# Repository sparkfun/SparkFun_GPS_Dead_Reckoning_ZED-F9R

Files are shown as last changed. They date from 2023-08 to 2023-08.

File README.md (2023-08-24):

SparkFun GPS-RTK Dead Reckoning Breakout - ZED-F9R, u.FL and SMA (Qwiic)
========================================

<table class="table table-hover table-striped table-bordered">
  <tr align="center">
   <td><a href="https://www.sparkfun.com/products/22693">SparkFun GPS-RTK Dead Reckoning Breakout - ZED-F9R (Qwiic)</a></td>
   <td><a href="https://www.sparkfun.com/products/22660">SparkFun GPS-RTK Dead Reckoning Breakout - ZED-F9R, SMA (Qwiic)</a></td>
  </tr>
  <tr align="center">
   <td><i>SparkFun GPS-RTK Dead Reckoning Breakout <br /> - ZED-F9R, u.FL (Qwiic) [<a href="https://www.sparkfun.com/products/22693">22693</a>]</i></td>
   <td><i>SparkFun GPS-RTK Dead Reckoning Breakout <br /> - ZED-F9R, SMA (Qwiic) [<a href="https://www.sparkfun.com/products/22660">GPS-22660</a>]</i></td>
  </tr>
</table>

The SparkFun GPS-RTK Dead Reckoning ZED-F9R Breakout (u.FL and SMA) is a high precision, sensor fusion GPS board with equally impressive configuration options and takes advantage of u-blox's Automotive Dead Reckoning (ADR) technology. The ZED-F9R module provides a highly accurate and continuous position by fusing a 3D IMU sensor, wheel ticks, a vehicle dynamics model, correction data, and GNSS measurements.

The ZED-F9R module is a 184-channel u-blox F9 engine GNSS receiver, meaning it can receive signals from the GPS, GLONASS, Galileo, and BeiDou constellations with ~0.2 meter accuracy! That's right, such accuracy can be achieved with an RTK navigation solution when used with a correction source. Note that the ZED-F9R can only operate as a rover, so you will need to connect to a base station. The module supports concurrent reception of four GNSS systems. The combination of GNSS and integrated 3D sensor measurements on the ZED-F9R provide accurate, real-time positioning rates of up to 30Hz.

Compared to other GPS modules, this breakout maximizes position accuracy in dense cities or covered areas. Even under poor signal conditions, continuous positioning is provided in urban environments and is also available during complete signal loss (e.g. short tunnels and parking garages). The ZED-F9R is the ultimate solution for autonomous robotic applications that require accurate positioning under challenging conditions.

Additionally, this u-blox receiver supports I2C (u-blox calls this Display Data Channel) which makes it perfect for the Qwiic compatibility so we don't have to use up our precious UART ports. Utilizing our handy Qwiic system, no soldering is required to connect it to the rest of your system. However, we still have broken out 0.1"-spaced pins in case you prefer to use a breadboard.

U-blox based GPS products are configurable using the popular, but dense, windows program called u-center. Plenty of different functions can be configured on the ZED-F9R: baud rates, update rates, geofencing, spoofing detection, external interrupts, SBAS/D-GPS, etc. All of this can be done within the SparkFun Arduino Library!

The SparkFun ZED-F9R GPS Breakout is also equipped with an on-board rechargeable battery that provides power to the RTC on the ZED-F9R. This reduces the time-to-first fix from a cold start (~24s) to a hot start (~2s). The battery will maintain RTC and GNSS orbit data without being connected to power for plenty of time.

Repository Contents
-------------------

* **/Documentation** - Data sheets, additional product information
* **/Hardware** - Eagle design files (.brd, .sch)
* **/Production** - Production panel files (.brd)

Documentation
--------------
* **[Library](https://github.com/sparkfun/SparkFun_u-blox_GNSS_v3)** - Arduino library v3 for the ZED-F9R.
    * _**Note**: We support two versions of the SparkFun u-blox GNSS library. [Version 2](https://github.com/sparkfun/SparkFun_u-blox_GNSS_Arduino_Library) and [Version 3](https://github.com/sparkfun/SparkFun_u-blox_GNSS_v3). Version 3 uses the u-blox Configuration Interface (VALSET and VALGET) to configure the module, instead of the deprecated UBX-CFG messages. For modules like the F9 and M10, we recommend upgrading to Version 3. However, older modules like the M8 do not support the Configuration Interface. For those you will need to keep using Version 2 of the library. We will continue to support both._
* **[Hookup Guide](https://learn.sparkfun.com/tutorials/1172)** - Basic hookup guide for the ZED-F9R.

Product Versions
----------------
* [GPS-22693](https://www.sparkfun.com/products/22693) - u.FL, v1.2
* [GPS-22660](https://www.sparkfun.com/products/22660) - SMA, V1.1
* [GPS-16344](https://www.sparkfun.com/products/16344) - u.FL, v1.0 initial release

Version History
---------------
* [v1.0](https://github.com/sparkfun/SparkFun_GPS_Dead_Reckoning_ZED-F9R/releases/tag/v1.0) - Initial Release

License Information
-------------------

This product is _**open source**_! 

Please review the LICENSE.md file for license information. 

If you have any questions or concerns on licensing, please contact technical support on our [SparkFun forums](https://forum.sparkfun.com/viewforum.php?f=152).

Distributed as-is; no warranty is given.

- Your friends at SparkFun.

_<COLLABORATION CREDIT>_

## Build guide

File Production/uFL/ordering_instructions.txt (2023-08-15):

panel size, 101x124mm
PCB thickness, 1.6mm
number of layers, 2
soldermask color, Red
silkscreen color, White
oz copper, 1oz
finish, HASL lead free
stencils, top
pcs per panel, 4
min trace width, 0.1524mm / 0.0060in
min drill size, 0.3048mm / 0.0120in

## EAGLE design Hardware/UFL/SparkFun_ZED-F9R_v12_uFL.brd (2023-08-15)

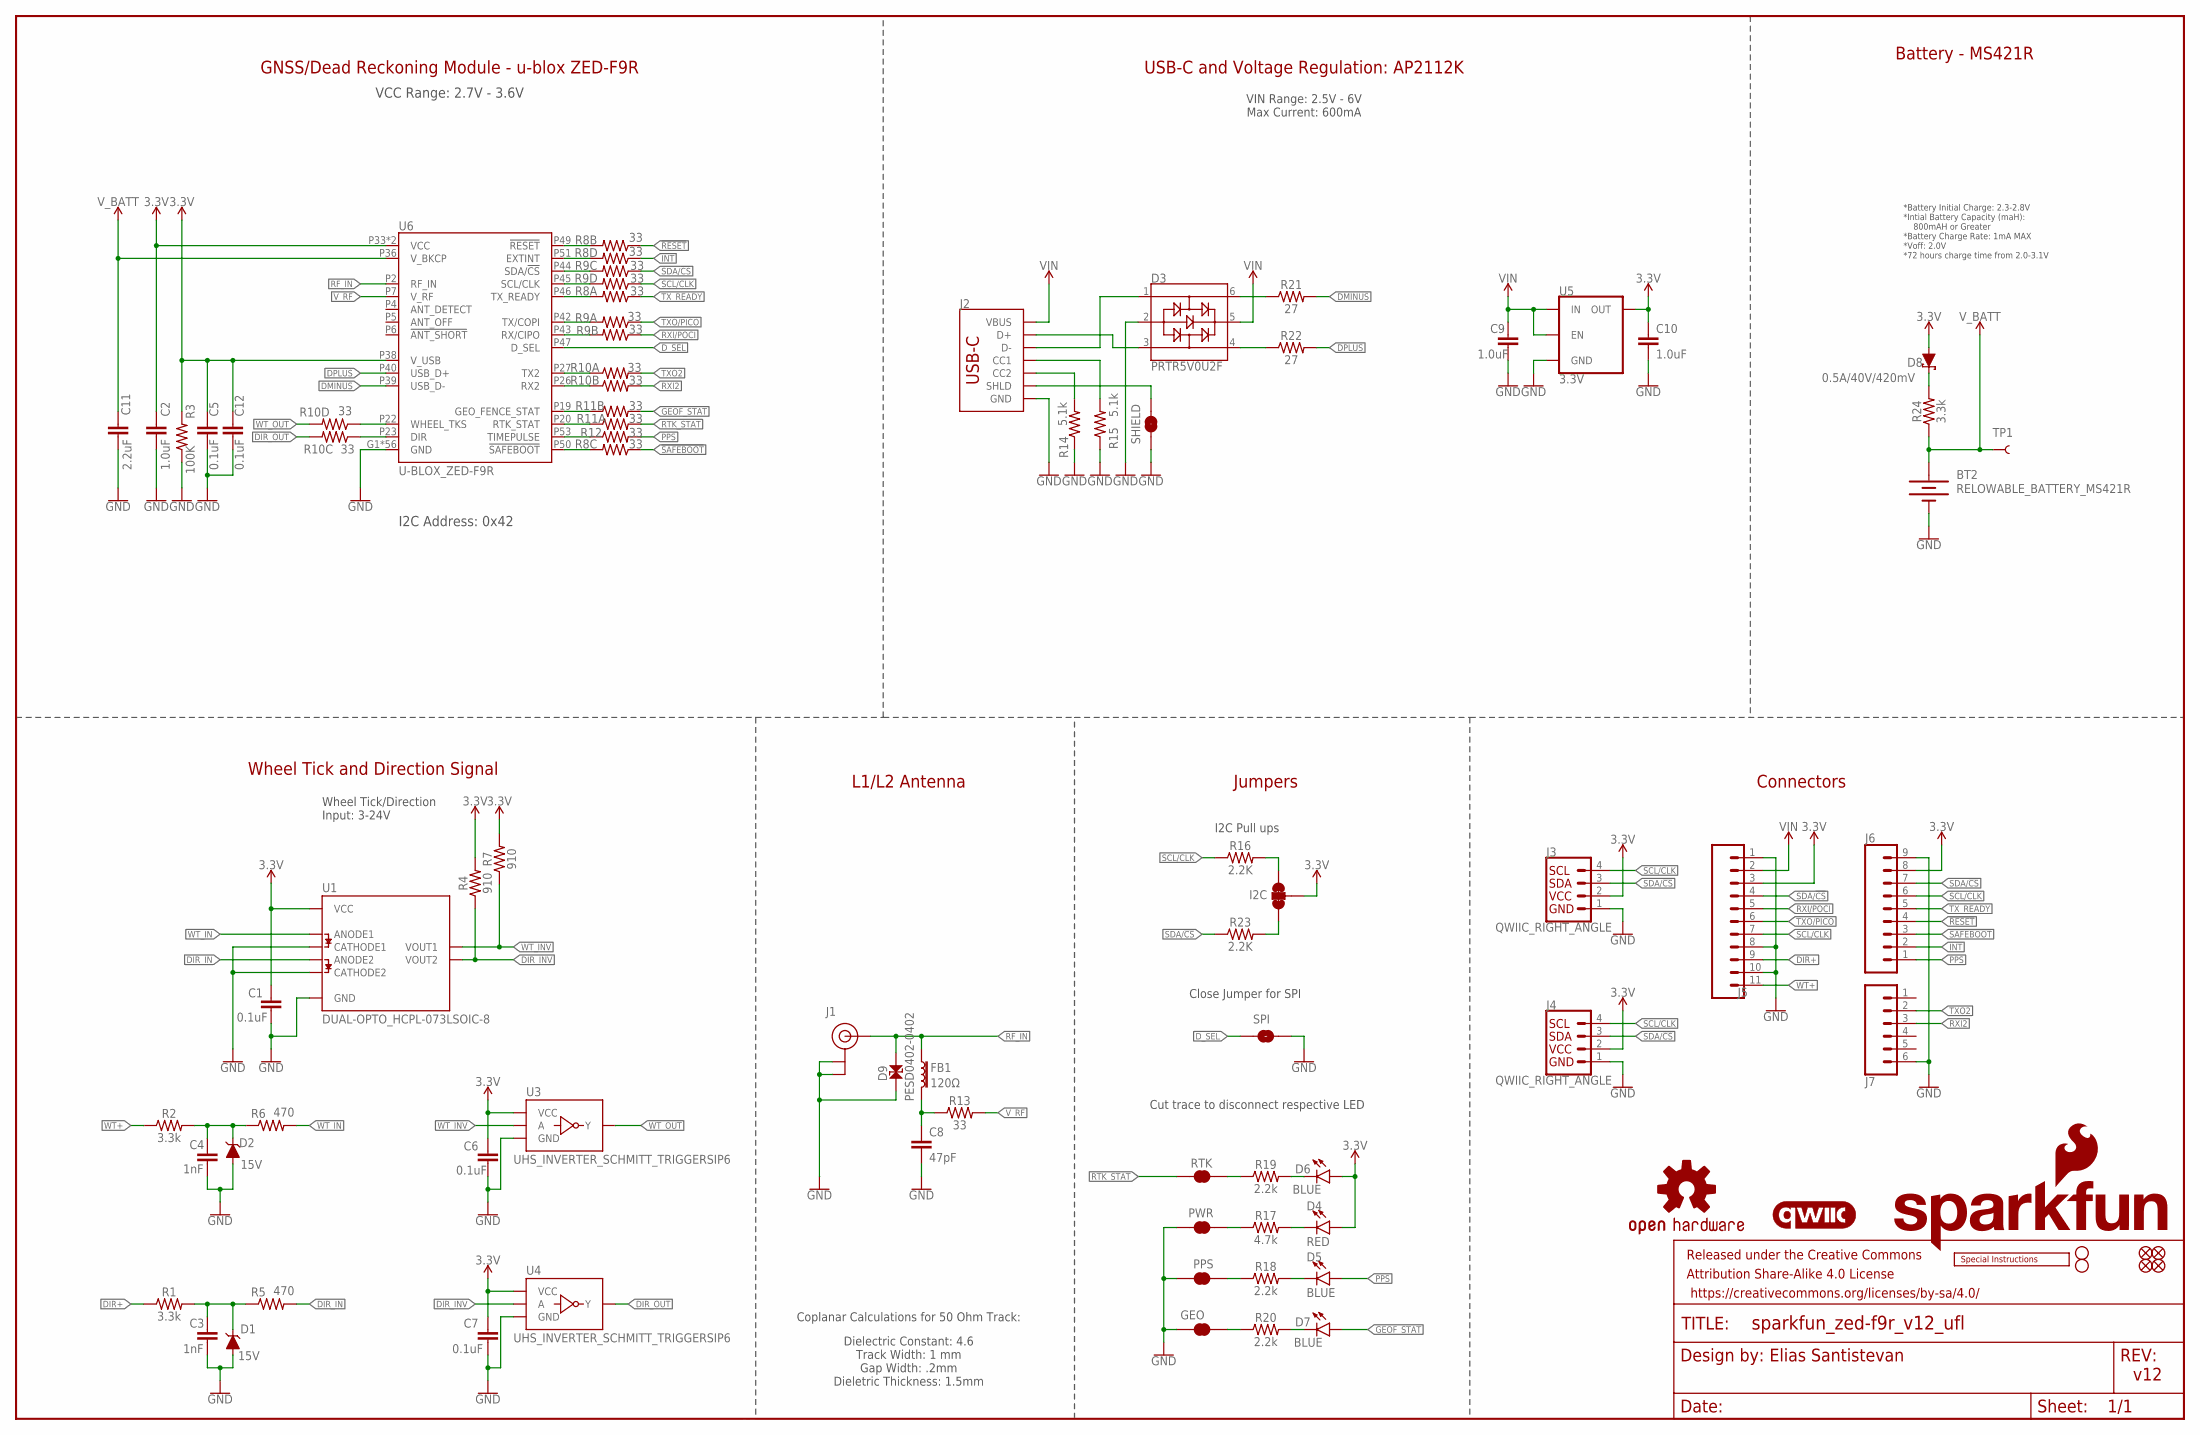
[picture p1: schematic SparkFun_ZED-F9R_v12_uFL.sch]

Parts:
$1_25_$_2020-03-30_22-52-05: STAND-OFFTIGHT; STAND-OFF-TIGHT
BT2: RELOWABLE_BATTERY_MS421R; MS421R_IV03E
C1, C5, C6, C7, C12: 0.1uF; 0402-TIGHT
C2, C9, C10: 1.0uF; 0402-TIGHT
C3, C4: 1nF; 0402
C8: 47pF; 0402
C11: 2.2uF; 0402-TIGHT
D1, D2: 15V; SOT23-3
D3: PRTR5V0U2F; SOT886
D4: RED; LED-0603
D5, D6, D7: BLUE; LED-0603
D8: 0.5A/40V/420mV; SOD-323
D9: PESD0402-0402; 0402
FB1: 120Ω; 0402
FD1, FD2, FD3, FD4: FIDUCIALUFIDUCIAL; FIDUCIAL-MICRO
FRAME1: FRAME-LEDGER; CREATIVE_COMMONS
GEO: JUMPER-SMT_2_NC_TRACE_SILK; SMT-JUMPER_2_NC_TRACE_SILK
H2: STAND-OFFTIGHT; STAND-OFF-TIGHT
I2C: JUMPER-SMT_3_2-NC_TRACE_SILK; SMT-JUMPER_3_2-NC_TRACE_SILK
J1: U.FL
J2: USB_C_2-LAYER_PADS; USB-C-16P-2LAYER-PADS
J3, J4: QWIIC_RIGHT_ANGLE; JST04_1MM_RA
J5: CONN_111X11_NO_SILK; 1X11_NO_SILK
J6: CONN_09NO_SILK; 1X09_NO_SILK
J7: CONN_06NO_SILK_NO_POP; 1X06_NO_SILK
LOGO1: OSHW-LOGOS; OSHW-LOGO-S
LOGO2: QWIIC_LOGO_4MM; QWIIC_4MM
LOGO3: SFE_LOGO_NAME_FLAME.2_INCH; SFE_LOGO_NAME_FLAME_.2
LOGO5: SPECIAL_INSTRUCTIONS-ORDERING; ORDERING_INSTRUCTIONS
PPS: JUMPER-SMT_2_NC_TRACE_SILK; SMT-JUMPER_2_NC_TRACE_SILK
PWR: JUMPER-SMT_2_NC_TRACE_SILK; SMT-JUMPER_2_NC_TRACE_SILK
R1, R2, R24: 3.3k; 0603
R3: 100K; 0402
R4, R7: 910; 0603
R5, R6: 470; 0603
R8, R9, R10, R11: 33; 1206_RA
R12, R13: 33; 0603
R14, R15: 5.1k; 0402
R16, R23: 2.2K; 0402
R17: 4.7k; 0603
R18, R19, R20: 2.2k; 0603
R21, R22: 27; 0603
RTK: JUMPER-SMT_2_NC_TRACE_SILK; SMT-JUMPER_2_NC_TRACE_SILK
SHIELD: JUMPER-SMT_2_NC_TRACE_SILK; SMT-JUMPER_2_NC_TRACE_SILK
SPI: JUMPER-SMT_2_NO_SILK; SMT-JUMPER_2_NO_SILK
TP1: TEST-POINT3X5; PAD.03X.05
U1: DUAL-OPTO_HCPL-073LSOIC-8; SO08
U3, U4: UHS_INVERTER_SCHMITT_TRIGGERSIP6; SIP6_MICROPAK2
U5: 3.3V; SOT23-5
U6: U-BLOX_ZED-F9R; UBLOX_ZED_F9R

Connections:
3.3V: C1.1, C2.1, C5.1, C6.1, C7.1, C10.1, C12.1, D4.A, D6.A, D8.A, I2C.2, J3.2, J4.2, J5.3, J6.8, R3.2, R4.2, R7.2, U1.8 (VCC), U3.P6 (VCC), U4.P6 (VCC), U5.5 (OUT), U6.P33 (VCC), U6.P34 (VCC), U6.P38 (V_USB)
!RESET: J6.4, R8.P2 (1)
!SAFEBOOT: J6.3, R8.P3 (1)
DIR+: J5.9, R1.1
DIR_IN: R5.2, U1.4 (ANODE2)
DIR_INV: R4.1, U1.6 (VOUT2), U4.P2 (A)
DIR_OUT: R10.P6 (2), U4.P4 (Y)
DMINUS: R21.2, U6.P39 (USB_D-)
DPLUS: R22.2, U6.P40 (USB_D+)
D_SEL: SPI.1, U6.P47 (D_SEL)
GEOF_STAT: D7.A, R11.P7 (2)
GND: BT2.-, C1.2, C2.2, C3.2, C4.2, C5.2, C6.2, C7.2, C8.2, C9.2, C10.2, C11.2, C12.2, D1.1 (A), D2.1 (A), D3.2, D9.1, GEO.1, J1.1 (GND), J1.2 (GND), J2.GND, J2.GND2 (GND), J3.1, J4.1, J5.1, J5.8, J5.10, J6.9, J7.6, PPS.1, PWR.1, R3.1, R14.1, R15.1, SHIELD.1, SPI.2, U1.2 (CATHODE1), U1.3 (CATHODE2), U1.5 (GND), U3.P3 (GND), U4.P3 (GND), U5.2 (GND), U6.G1 (GND), U6.G2 (GND), U6.G3 (GND), U6.G4 (GND), U6.G5 (GND), U6.G6 (GND), U6.G7 (GND), U6.G8 (GND), U6.G9 (GND), U6.G10 (GND), U6.G11 (GND), U6.G12 (GND), U6.G13 (GND), U6.G14 (GND), U6.G15 (GND), U6.G16 (GND), U6.G17 (GND), U6.G18 (GND), U6.G19 (GND), U6.G20 (GND), U6.G21 (GND), U6.G22 (GND), U6.G23 (GND), U6.G24 (GND), U6.G25 (GND), U6.G26 (GND), U6.G27 (GND), U6.G28 (GND), U6.G29 (GND), U6.G30 (GND), U6.G31 (GND), U6.G32 (GND), U6.G33 (GND), U6.G34 (GND), U6.G35 (GND), U6.G36 (GND), U6.G37 (GND), U6.G38 (GND), U6.G39 (GND), U6.G40 (GND), U6.G41 (GND), U6.G42 (GND), U6.G43 (GND), U6.G44 (GND), U6.G45 (GND), U6.G46 (GND), U6.G47 (GND), U6.G48 (GND), U6.P1 (GND), U6.P3 (GND), U6.P12 (GND), U6.P14 (GND), U6.P32 (GND), U6.P37 (GND), U6.P41 (GND), U6.P48 (GND)
INT: J6.2, R8.P4 (1)
unnamed: I2C.1, R23.2
unnamed: D8.C, R24.2
unnamed: I2C.3, R16.2
unnamed: D4.C, R17.2
unnamed: C8.1, FB1.2, R13.1
unnamed: D3.3, J2.A6 (D+), J2.B6 (D+)
unnamed: D3.1, J2.A7 (D-), J2.B7 (D-)
unnamed: PWR.2, R17.1
unnamed: D3.6, R21.1
unnamed: D3.4, R22.1
unnamed: R8.P7 (2), U6.P49 (!RESET!)
unnamed: R8.P5 (2), U6.P51 (EXTINT)
unnamed: J2.B5 (CC2), R14.2
unnamed: J2.A5 (CC1), R15.2
unnamed: R9.P6 (2), U6.P44 (SDA/!CS!)
unnamed: R9.P5 (2), U6.P45 (SCL/CLK)
unnamed: R8.P8 (2), U6.P46 (TX_READY)
unnamed: R9.P8 (2), U6.P42 (TX/COPI)
unnamed: R9.P7 (2), U6.P43 (RX/CIPO)
unnamed: R10.P1 (1), U6.P27 (TX2)
unnamed: R19.1, RTK.2
unnamed: PPS.2, R18.1
unnamed: D5.C, R18.2
unnamed: D6.C, R19.2
unnamed: R10.P2 (1), U6.P26 (RX2)
unnamed: R11.P2 (1), U6.P19 (GEO_FENCE_STAT)
unnamed: R11.P1 (1), U6.P20 (RTK_STAT)
unnamed: R12.1, U6.P53 (TIMEPULSE)
unnamed: R8.P6 (2), U6.P50 (!SAFEBOOT!)
unnamed: R10.P4 (1), U6.P22 (WHEEL_TKS)
unnamed: R10.P3 (1), U6.P23 (DIR)
unnamed: GEO.2, R20.1
unnamed: D7.C, R20.2
unnamed: C4.1, D2.3 (C), R2.2, R6.1
unnamed: C3.1, D1.3 (C), R1.2, R5.1
PPS: D5.A, J6.1, R12.2
RF_IN: D9.2, FB1.1, J1.FEED (SIGNAL), U6.P2 (RF_IN)
RTK_STAT: R11.P8 (2), RTK.1
RXI2: J7.3, R10.P7 (2)
RXI/POCI: J5.5, R9.P2 (1)
SCL/CLK: J3.4, J4.4, J5.7, J6.6, R9.P4 (1), R16.1
SDA/!CS: J3.3, J4.3, J5.4, J6.7, R9.P3 (1), R23.1
SHIELD: J2.SHLD1 (SHLD), J2.SHLD2 (SHLD), J2.SHLD3 (SHLD), J2.SHLD4 (SHLD), SHIELD.2
TXO2: J7.2, R10.P8 (2)
TXO/PICO: J5.6, R9.P1 (1)
TX_READY: J6.5, R8.P1 (1)
VIN: C9.1, D3.5, J2.VBUS1 (VBUS), J2.VBUS2 (VBUS), J5.2, U5.1 (IN), U5.3 (EN)
V_BATT: BT2.+, C11.1, R24.1, TP1.1, U6.P36 (V_BKCP)
V_RF: R13.2, U6.P7 (V_RF)
WT+: J5.11, R2.1
WT_IN: R6.2, U1.1 (ANODE1)
WT_INV: R7.1, U1.7 (VOUT1), U3.P2 (A)
WT_OUT: R10.P5 (2), U3.P4 (Y)

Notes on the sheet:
v12
Elias Santistevan
GNSS/Dead Reckoning Module - u-blox ZED-F9R
Battery - MS421R
Connectors
Jumpers
Close Jumper for SPI
I2C Pull ups
Cut trace to disconnect respective LED
L1/L2 Antenna
*Battery Initial Charge: 2.3-2.8V *Intial Battery Capacity (maH): 800mAH or Greater *Battery Charge Rate: 1mA MAX *Voff: 2.0V *72 hours charge time from 2.0-3.1V
VIN Range: 2.5V - 6V Max Current: 600mA
USB-C and Voltage Regulation: AP2112K
VCC Range: 2.7V - 3.6V
I2C Address: 0x42
Wheel Tick and Direction Signal
Wheel Tick/Direction Input: 3-24V
Coplanar Calculations for 50 Ohm Track:
Dielectric Constant: 4.6 Track Width: 1 mm Gap Width: .2mm Dieletric Thickness: 1.5mm

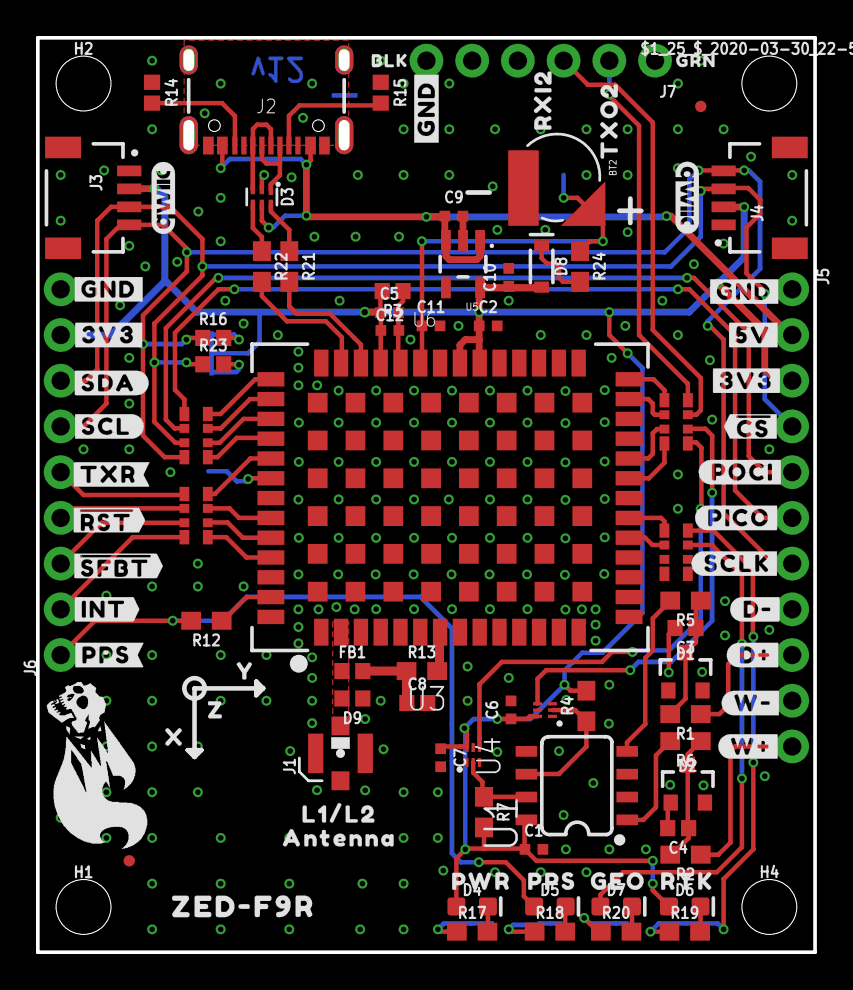
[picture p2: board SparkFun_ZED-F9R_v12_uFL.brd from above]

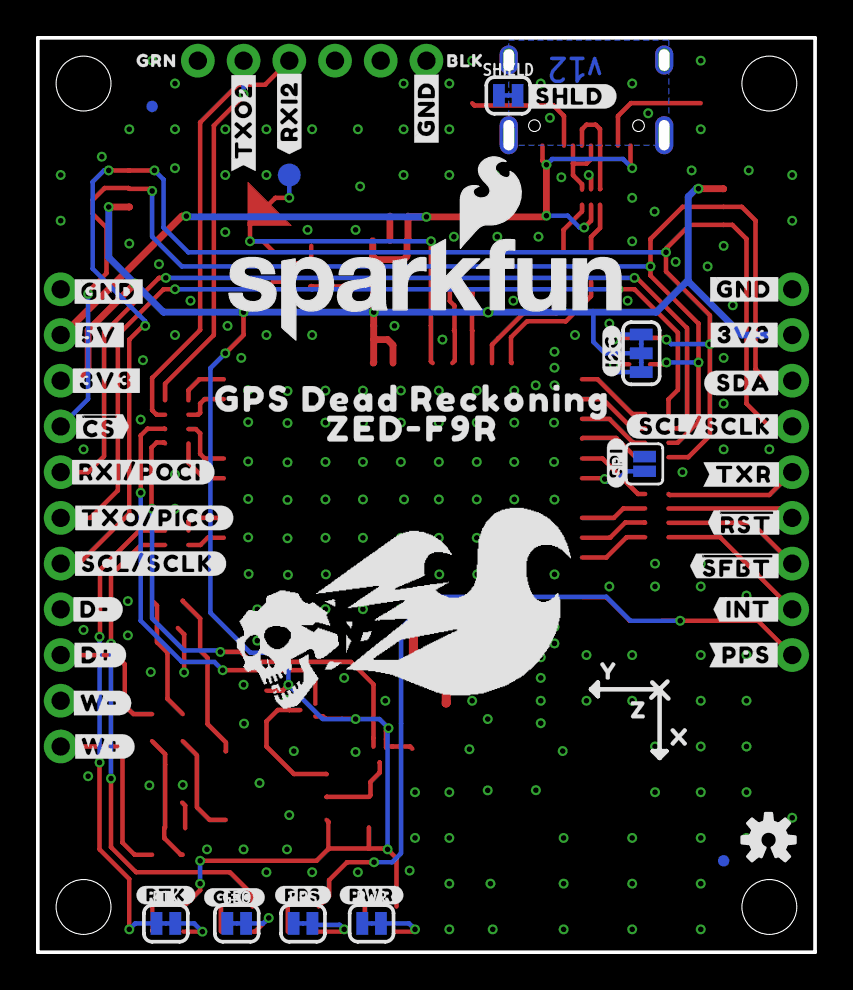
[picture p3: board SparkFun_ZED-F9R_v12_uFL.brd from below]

Board: 2 copper layers, 43.2 x 50.8 mm, 155 parts (50 on the bottom side), 66 nets.

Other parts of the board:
H1, H4: STAND-OFFTIGHT; STAND-OFF-TIGHT
LOGO4: QWIIC_LOGO_4MM; QWIIC_4MM
U$1: ZED#F9R21
U$2: L1#L26
U$3: ANTENNA6
U$4, U$32: X17
U$5, U$6, U$7, U$8, U$9, U$67: #GND#16
U$10: #D##241
U$11: #D##240
U$12: #W##244
U$13: #W##245
U$14, U$15, U$16, U$17: #3V3#17
U$18, U$21: #5V#17
U$19, U$20: DEAD#RECKONING#GPS#BOARD#SILK#FINAL#JPG
U$22: #SDA#235
U$23, U$71: BLK18
U$24: ##CS##25
U$26, U$70: GRN19
U$27: #SDA#236
U$28: #SCL#238
U$29: #TXR#248
U$30: ##RST##28
U$31: ##SFBT##26
U$33: #INT#1
U$34: #INT#0
U$35: #PPS#3
U$37: #SCLK#233
U$38: RXI229
U$39: PWR6
U$40: RTK12
U$41: GEO10
U$42: PPS8
U$43, U$44: Z19
U$45, U$49: Y18
U$46: #SCL#SCLK#2244
U$47: #GEO#12
U$48: #RTK#14
U$50: TXO2234
U$51: #PPS#10
U$52: ##CS##26
U$53: #SPI#4
U$54: #I2C#5
U$57: #SCL#SCLK#2243
U$58: #D##2249
U$59: #D##2248
U$60: #W##2253
U$61: #W##2252
U$62: #TXR#2255
U$63: ##RST##27
U$64: ##SFBT##29
U$65: #PPS#2
U$66: #PWR#8
U$68: #RXI2#34
U$69: #TXO2#235
U$72: GPS_DEAD_RECKONING24
U$73: ZED#F9R25
U$74: #SHLD#2258
U$75: #PICO#2
U$76: #POCI#3
U$77: #RXI#POCI#15
U$78: #TXO#PICO#16

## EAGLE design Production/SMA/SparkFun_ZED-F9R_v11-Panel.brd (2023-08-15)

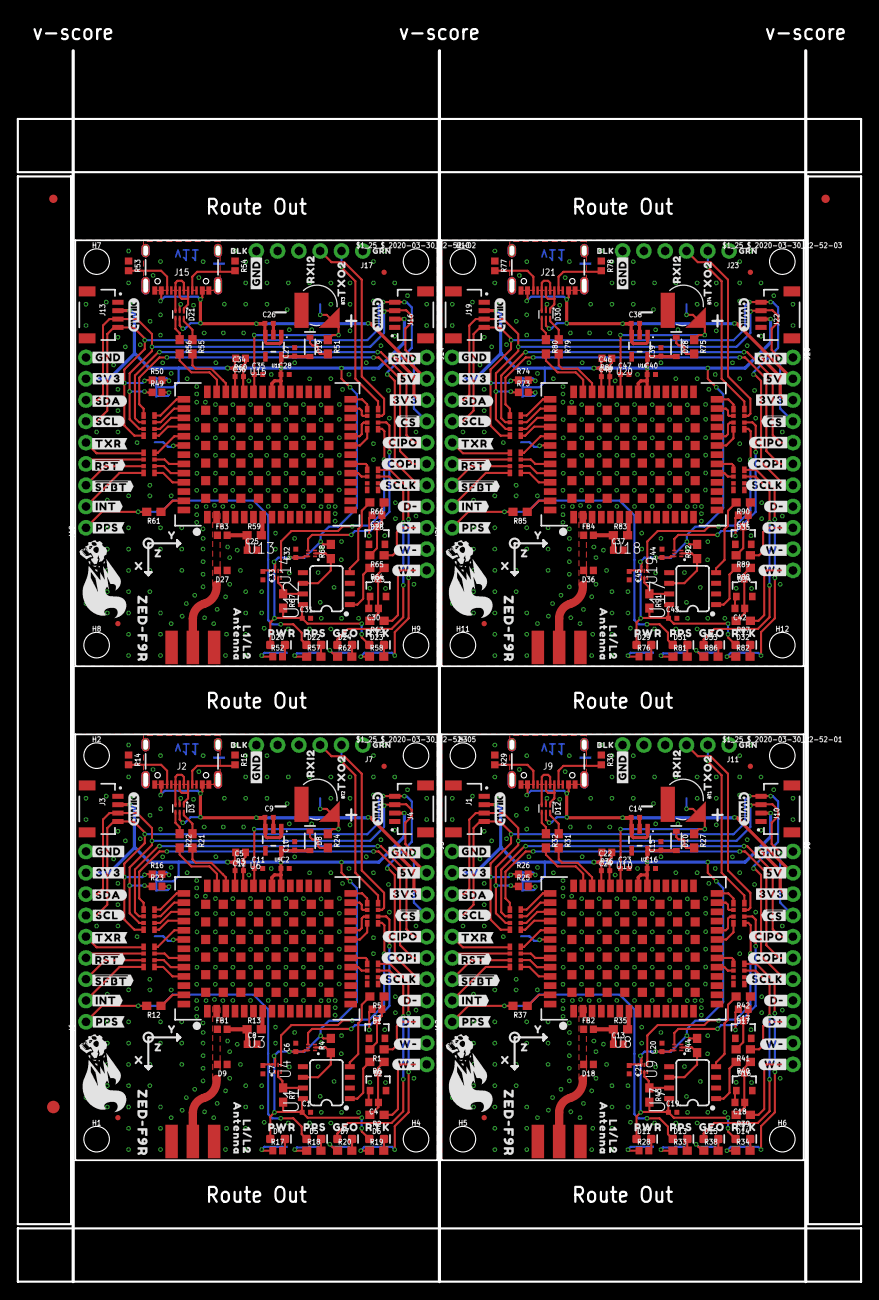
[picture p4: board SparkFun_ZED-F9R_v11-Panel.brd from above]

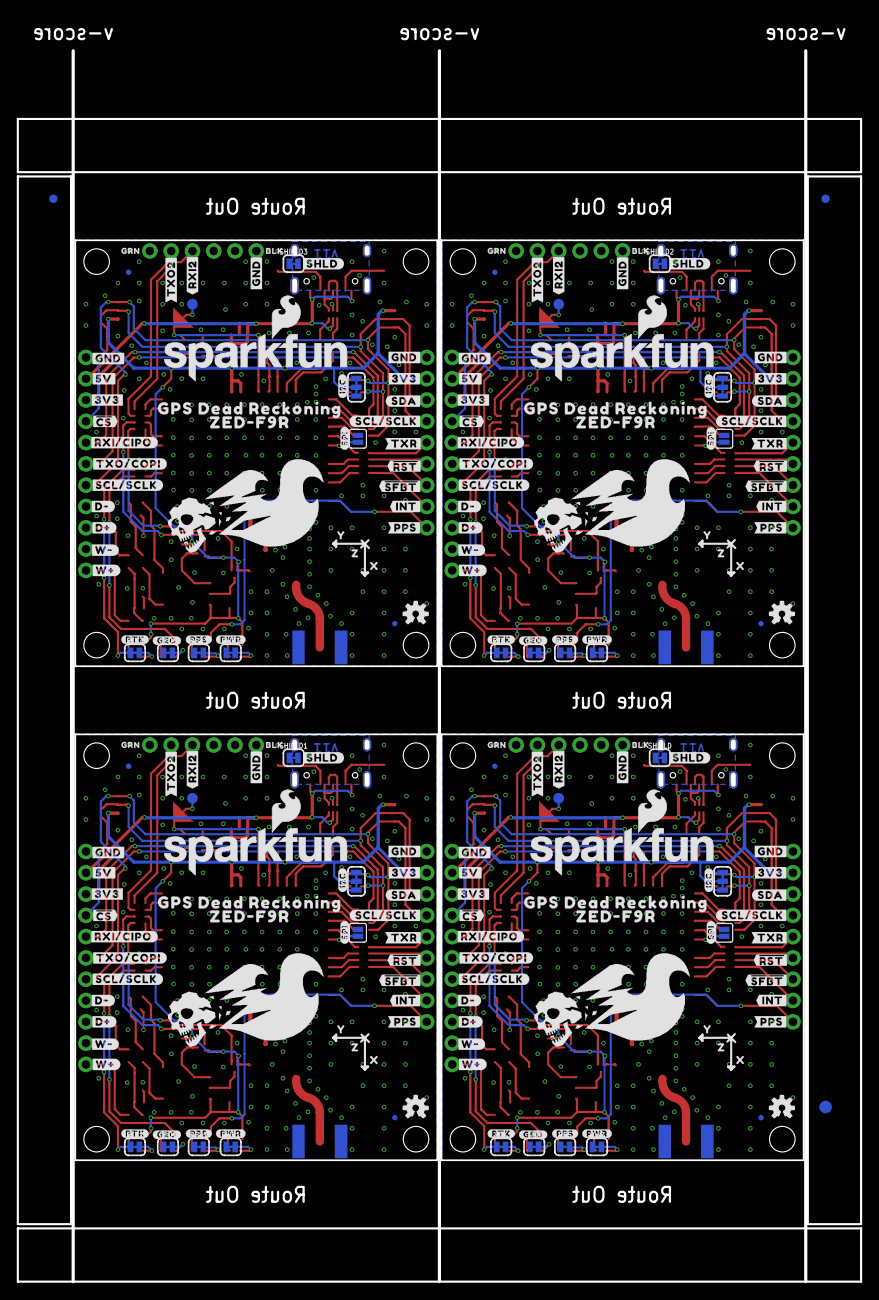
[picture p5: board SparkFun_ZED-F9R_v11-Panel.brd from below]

Board: 2 copper layers, 100.6 x 146.8 mm, 618 parts (203 on the bottom side), 264 nets.

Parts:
$1_25_$_2020-03-30_22-52-01, $1_25_$_2020-03-30_22-52-02, $1_25_$_2020-03-30_22-52-03, $1_25_$_2020-03-30_22-52-05: STAND-OFFTIGHT; STAND-OFF-TIGHT
BT1, BT2, BT3, BT4: RELOWABLE_BATTERY_MS421R; MS421R_IV03E
C1, C5, C6, C7, C12, C19, C20, C21, C22, C24, C31, C32, C33, C34, C36, C43, C44, C45, C46, C48: 0.1uF; 0402-TIGHT
C2, C9, C10, C14, C15, C16, C26, C27, C28, C38, C39, C40: 1.0uF; 0402-TIGHT
C3, C4, C17, C18, C29, C30, C41, C42: 1nF; 0402
C8, C13, C25, C37: 47pF; 0402
C11, C23, C35, C47: 2.2uF; 0402-TIGHT
D1, D2, D16, D17, D25, D26, D34, D35: 15V; SOT23-3
D3, D12, D21, D30: PRTR5V0U2F; SOT886
D4, D11, D20, D29: RED; LED-0603
D5, D6, D7, D13, D14, D15, D22, D23, D24, D31, D32, D33: BLUE; LED-0603
D8, D10, D19, D28: 0.5A/40V/420mV; SOD-323
D9, D18, D27, D36: PESD0402-0402; 0402
E1, E2, E3, E4: ANTENNA-SMA-GROUNDEDEDGE_SMA; SMA-EDGE
E$1, E$2, E$3, E$4: FIDUCIAL-1X2
E$5, E$6: FIDUCIAL-1.5X3
FB1, FB2, FB3, FB4: 120Ω; 0402
FD1, FD2, FD3, FD4, FD5, FD6, FD7, FD8, FD9, FD10, FD11, FD12, FD13, FD14, FD15, FD16: FIDUCIALUFIDUCIAL; FIDUCIAL-MICRO
GEO, GEO1, GEO2, GEO3: JUMPER-SMT_2_NC_TRACE_SILK; SMT-JUMPER_2_NC_TRACE_SILK
H1, H2, H3, H4, H5, H6, H7, H8, H9, H10, H11, H12: STAND-OFFTIGHT; STAND-OFF-TIGHT
I2C, I2C1, I2C2, I2C3: JUMPER-SMT_3_2-NC_TRACE_SILK; SMT-JUMPER_3_2-NC_TRACE_SILK
J1, J3, J4, J10, J13, J16, J19, J22: QWIIC_RIGHT_ANGLE; JST04_1MM_RA
J2, J9, J15, J21: USB-C-16P-2LAYER-PADS
J5, J8, J14, J20: 1X11_NO_SILK
J6, J12, J18, J24: 1X09_NO_SILK
J7, J11, J17, J23: 1X06_NO_SILK
LOGO1, LOGO7, LOGO11, LOGO15: OSHW-LOGOS; OSHW-LOGO-S
LOGO2, LOGO4, LOGO6, LOGO8, LOGO10, LOGO12, LOGO14, LOGO16: QWIIC_LOGO_4MM; QWIIC_4MM
LOGO3, LOGO5, LOGO9, LOGO13: SFE_LOGO_NAME_FLAME.2_INCH; SFE_LOGO_NAME_FLAME_.2
PPS, PPS1, PPS2, PPS3: JUMPER-SMT_2_NC_TRACE_SILK; SMT-JUMPER_2_NC_TRACE_SILK
PWR, PWR1, PWR2, PWR3: JUMPER-SMT_2_NC_TRACE_SILK; SMT-JUMPER_2_NC_TRACE_SILK
R1, R2, R24, R27, R39, R41, R51, R63, R65, R75, R87, R89: 3.3k; 0603
R3, R36, R60, R84: 100K; 0402
R4, R7, R43, R44, R67, R68, R91, R92: 910; 0603
R5, R6, R40, R42, R64, R66, R88, R90: 470; 0603
R8, R9, R10, R11, R45, R46, R47, R48, R69, R70, R71, R72, R93, R94, R95, R96: 33; 1206_RA
R12, R13, R35, R37, R59, R61, R83, R85: 33; 0603
R14, R15, R29, R30, R53, R54, R77, R78: 5.1k; 0402
R16, R23, R25, R26, R49, R50, R73, R74: 2.2K; 0402
R17, R28, R52, R76: 1KOHM-0402-1/16W-1%; 0402
R18, R19, R20, R33, R34, R38, R57, R58, R62, R81, R82, R86: 2.2k; 0603
R21, R22, R31, R32, R55, R56, R79, R80: 27; 0603
RTK, RTK1, RTK2, RTK3: JUMPER-SMT_2_NC_TRACE_SILK; SMT-JUMPER_2_NC_TRACE_SILK
SHIELD, SHIELD1, SHIELD2, SHIELD3: JUMPER-SMT_2_NC_TRACE_SILK; SMT-JUMPER_2_NC_TRACE_SILK
SPI, SPI1, SPI2, SPI3: JUMPER-SMT_2_NO_SILK; SMT-JUMPER_2_NO_SILK
TP1, TP2, TP3, TP4: TEST-POINT3X5; PAD.03X.05
U1, U7, U12, U17: DUAL-OPTO_HCPL-073LSOIC-8; SO08
U2, U5, U11, U16: 3.3V; SOT23-5
U3, U4, U8, U9, U13, U14, U18, U19: UHS_INVERTER_SCHMITT_TRIGGERSIP6; SIP6_MICROPAK2
U6, U10, U15, U20: U-BLOX_ZED-F9R; UBLOX_ZED_F9R
U$1, U$108, U$182, U$256: ZED#F9R21
U$2, U$109, U$183, U$257: L1#L26
U$3, U$110, U$184, U$258: ANTENNA6
U$4, U$32, U$111, U$112, U$185, U$186, U$259, U$260: X17
U$5, U$6, U$7, U$8, U$9, U$67, U$77, U$78, U$79, U$80, U$81, U$137, U$151, U$152, U$153, U$154, U$155, U$211, U$225, U$226, U$227, U$228, U$229, U$285: #GND#16
U$10, U$97, U$171, U$245: #D##241
U$11, U$98, U$172, U$246: #D##240
U$12, U$99, U$173, U$247: #W##244
U$13, U$100, U$174, U$248: #W##245
U$14, U$15, U$16, U$17, U$82, U$83, U$84, U$85, U$156, U$157, U$158, U$159, U$230, U$231, U$232, U$233: #3V3#17
U$18, U$21, U$86, U$87, U$160, U$161, U$234, U$235: #5V#17
U$19, U$20, U$75, U$76, U$149, U$150, U$223, U$224: DEAD#RECKONING#GPS#BOARD#SILK#FINAL#JPG
U$22, U$88, U$162, U$236: #SDA#235
U$23, U$71, U$102, U$141, U$176, U$215, U$250, U$289: BLK18
U$24, U$119, U$193, U$267: ##CS##25
U$25, U$94, U$168, U$242: #COPI#230
U$26, U$70, U$103, U$140, U$177, U$214, U$251, U$288: GRN19
U$27, U$89, U$163, U$237: #SDA#236
U$28, U$90, U$164, U$238: #SCL#238
U$29, U$91, U$165, U$239: #TXR#248
U$30, U$118, U$192, U$266: ##RST##28
U$31, U$92, U$166, U$240: ##SFBT##26
U$33, U$145, U$219, U$293: #INT#1
U$34, U$146, U$220, U$294: #INT#0
U$35, U$93, U$167, U$241: #PPS#3
U$36, U$95, U$169, U$243: #CIPO#232
U$37, U$96, U$170, U$244: #SCLK#233
U$38, U$101, U$175, U$249: RXI229
U$39, U$104, U$178, U$252: PWR6
U$40, U$105, U$179, U$253: RTK12
U$41, U$106, U$180, U$254: GEO10
U$42, U$107, U$181, U$255: PPS8
U$43, U$44, U$113, U$114, U$187, U$188, U$261, U$262: Z19
U$45, U$49, U$115, U$116, U$189, U$190, U$263, U$264: Y18
U$46, U$130, U$204, U$278: #SCL#SCLK#2244
U$47, U$131, U$205, U$279: #GEO#12
U$48, U$132, U$206, U$280: #RTK#14
U$50, U$117, U$191, U$265: TXO2234
U$51, U$133, U$207, U$281: #PPS#10
U$52, U$120, U$194, U$268: ##CS##26
U$53, U$136, U$210, U$284: #SPI#4
U$54, U$135, U$209, U$283: #I2C#5
U$55, U$147, U$221, U$295: #RXI#CIPO#32
U$56, U$148, U$222, U$296: #TXO#COPI#33
U$57, U$121, U$195, U$269: #SCL#SCLK#2243
U$58, U$122, U$196, U$270: #D##2249
U$59, U$123, U$197, U$271: #D##2248
U$60, U$124, U$198, U$272: #W##2253
U$61, U$125, U$199, U$273: #W##2252
U$62, U$126, U$200, U$274: #TXR#2255
U$63, U$127, U$201, U$275: ##RST##27
U$64, U$128, U$202, U$276: ##SFBT##29
U$65, U$129, U$203, U$277: #PPS#2
U$66, U$134, U$208, U$282: #PWR#8
U$68, U$138, U$212, U$286: #RXI2#34
U$69, U$139, U$213, U$287: #TXO2#235
U$72, U$142, U$216, U$290: GPS_DEAD_RECKONING24
U$73, U$143, U$217, U$291: ZED#F9R25
U$74, U$144, U$218, U$292: #SHLD#2258

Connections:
3.3V: C1.1, C2.1, C5.1, C6.1, C7.1, C10.1, C12.1, D4.A, D6.A, D8.A, I2C.2, J3.2, J4.2, J5.3, J6.8, R3.2, R4.2, R7.2, U1.8, U3.P6, U4.P6, U5.5, U6.P33, U6.P34, U6.P38
3.3V1: C15.1, C16.1, C19.1, C20.1, C21.1, C22.1, C24.1, D10.A, D11.A, D14.A, I2C1.2, J1.2, J8.3, J10.2, J12.8, R36.2, R43.2, R44.2, U2.5, U7.8, U8.P6, U9.P6, U10.P33, U10.P34, U10.P38
3.3V2: C27.1, C28.1, C31.1, C32.1, C33.1, C34.1, C36.1, D19.A, D20.A, D23.A, I2C2.2, J13.2, J14.3, J16.2, J18.8, R60.2, R67.2, R68.2, U11.5, U12.8, U13.P6, U14.P6, U15.P33, U15.P34, U15.P38
3.3V3: C39.1, C40.1, C43.1, C44.1, C45.1, C46.1, C48.1, D28.A, D29.A, D32.A, I2C3.2, J19.2, J20.3, J22.2, J24.8, R84.2, R91.2, R92.2, U16.5, U17.8, U18.P6, U19.P6, U20.P33, U20.P34, U20.P38
!RESET: J6.4, R8.P2
!RESET1: J12.4, R46.P2
!RESET2: J18.4, R70.P2
!RESET3: J24.4, R94.P2
!SAFEBOOT: J6.3, R8.P3
!SAFEBOOT1: J12.3, R46.P3
!SAFEBOOT2: J18.3, R70.P3
!SAFEBOOT3: J24.3, R94.P3
DIR+: J5.9, R1.1
DIR+1: J8.9, R41.1
DIR+2: J14.9, R65.1
DIR+3: J20.9, R89.1
DIR_IN: R5.2, U1.4
DIR_IN1: R42.2, U7.4
DIR_IN2: R66.2, U12.4
DIR_IN3: R90.2, U17.4
DIR_INV: R4.1, U1.6, U4.P2
DIR_INV1: R44.1, U7.6, U9.P2
DIR_INV2: R68.1, U12.6, U14.P2
DIR_INV3: R92.1, U17.6, U19.P2
DIR_OUT: R10.P6, U4.P4
DIR_OUT1: R47.P6, U9.P4
DIR_OUT2: R71.P6, U14.P4
DIR_OUT3: R95.P6, U19.P4
DMINUS: R21.2, U6.P39
DMINUS1: R31.2, U10.P39
DMINUS2: R55.2, U15.P39
DMINUS3: R79.2, U20.P39
DPLUS: R22.2, U6.P40
DPLUS1: R32.2, U10.P40
DPLUS2: R56.2, U15.P40
DPLUS3: R80.2, U20.P40
D_SEL: SPI.1, U6.P47
D_SEL1: SPI1.1, U10.P47
D_SEL2: SPI2.1, U15.P47
D_SEL3: SPI3.1, U20.P47
GEOF_STAT: D7.A, R11.P7
GEOF_STAT1: D15.A, R48.P7
GEOF_STAT2: D24.A, R72.P7
GEOF_STAT3: D33.A, R96.P7
GND: BT2.-, C1.2, C2.2, C3.2, C4.2, C5.2, C6.2, C7.2, C8.2, C9.2, C10.2, C11.2, C12.2, D1.1, D2.1, D3.2, D9.1, E1.GND@0, E1.GND@1, E1.GND@2, E1.GND@3, GEO.1, J2.GND, J2.GND2, J3.1, J4.1, J5.1, J5.8, J5.10, J6.9, J7.6, PPS.1, PWR.1, R3.1, R14.1, R15.1, SHIELD.1, SPI.2, U1.2, U1.3, U1.5, U3.P3, U4.P3, U5.2, U6.G1, U6.G2, U6.G3, U6.G4, U6.G5, U6.G6, U6.G7, U6.G8, U6.G9, U6.G10, U6.G11, U6.G12, U6.G13, U6.G14, U6.G15, U6.G16, U6.G17, U6.G18, U6.G19, U6.G20, U6.G21, U6.G22, U6.G23, U6.G24, U6.G25, U6.G26, U6.G27, U6.G28, U6.G29, U6.G30, U6.G31, U6.G32, U6.G33, U6.G34, U6.G35, U6.G36, U6.G37, U6.G38, U6.G39, U6.G40, U6.G41, U6.G42, U6.G43, U6.G44, U6.G45, U6.G46, U6.G47, U6.G48, U6.P1, U6.P3, U6.P12, U6.P14, U6.P32, U6.P37, U6.P41, U6.P48
GND1: BT1.-, C13.2, C14.2, C15.2, C16.2, C17.2, C18.2, C19.2, C20.2, C21.2, C22.2, C23.2, C24.2, D12.2, D16.1, D17.1, D18.1, E2.GND@0, E2.GND@1, E2.GND@2, E2.GND@3, GEO1.1, J1.1, J8.1, J8.8, J8.10, J9.GND, J9.GND2, J10.1, J11.6, J12.9, PPS1.1, PWR1.1, R29.1, R30.1, R36.1, SHIELD1.1, SPI1.2, U2.2, U7.2, U7.3, U7.5, U8.P3, U9.P3, U10.G1, U10.G2, U10.G3, U10.G4, U10.G5, U10.G6, U10.G7, U10.G8, U10.G9, U10.G10, U10.G11, U10.G12, U10.G13, U10.G14, U10.G15, U10.G16, U10.G17, U10.G18, U10.G19, U10.G20, U10.G21, U10.G22, U10.G23, U10.G24, U10.G25, U10.G26, U10.G27, U10.G28, U10.G29, U10.G30, U10.G31, U10.G32, U10.G33, U10.G34, U10.G35, U10.G36, U10.G37, U10.G38, U10.G39, U10.G40, U10.G41, U10.G42, U10.G43, U10.G44, U10.G45, U10.G46, U10.G47, U10.G48, U10.P1, U10.P3, U10.P12, U10.P14, U10.P32, U10.P37, U10.P41, U10.P48
GND2: BT3.-, C25.2, C26.2, C27.2, C28.2, C29.2, C30.2, C31.2, C32.2, C33.2, C34.2, C35.2, C36.2, D21.2, D25.1, D26.1, D27.1, E3.GND@0, E3.GND@1, E3.GND@2, E3.GND@3, GEO2.1, J13.1, J14.1, J14.8, J14.10, J15.GND, J15.GND2, J16.1, J17.6, J18.9, PPS2.1, PWR2.1, R53.1, R54.1, R60.1, SHIELD2.1, SPI2.2, U11.2, U12.2, U12.3, U12.5, U13.P3, U14.P3, U15.G1, U15.G2, U15.G3, U15.G4, U15.G5, U15.G6, U15.G7, U15.G8, U15.G9, U15.G10, U15.G11, U15.G12, U15.G13, U15.G14, U15.G15, U15.G16, U15.G17, U15.G18, U15.G19, U15.G20, U15.G21, U15.G22, U15.G23, U15.G24, U15.G25, U15.G26, U15.G27, U15.G28, U15.G29, U15.G30, U15.G31, U15.G32, U15.G33, U15.G34, U15.G35, U15.G36, U15.G37, U15.G38, U15.G39, U15.G40, U15.G41, U15.G42, U15.G43, U15.G44, U15.G45, U15.G46, U15.G47, U15.G48, U15.P1, U15.P3, U15.P12, U15.P14, U15.P32, U15.P37, U15.P41, U15.P48
GND3: BT4.-, C37.2, C38.2, C39.2, C40.2, C41.2, C42.2, C43.2, C44.2, C45.2, C46.2, C47.2, C48.2, D30.2, D34.1, D35.1, D36.1, E4.GND@0, E4.GND@1, E4.GND@2, E4.GND@3, GEO3.1, J19.1, J20.1, J20.8, J20.10, J21.GND, J21.GND2, J22.1, J23.6, J24.9, PPS3.1, PWR3.1, R77.1, R78.1, R84.1, SHIELD3.1, SPI3.2, U16.2, U17.2, U17.3, U17.5, U18.P3, U19.P3, U20.G1, U20.G2, U20.G3, U20.G4, U20.G5, U20.G6, U20.G7, U20.G8, U20.G9, U20.G10, U20.G11, U20.G12, U20.G13, U20.G14, U20.G15, U20.G16, U20.G17, U20.G18, U20.G19, U20.G20, U20.G21, U20.G22, U20.G23, U20.G24, U20.G25, U20.G26, U20.G27, U20.G28, U20.G29, U20.G30, U20.G31, U20.G32, U20.G33, U20.G34, U20.G35, U20.G36, U20.G37, U20.G38, U20.G39, U20.G40, U20.G41, U20.G42, U20.G43, U20.G44, U20.G45, U20.G46, U20.G47, U20.G48, U20.P1, U20.P3, U20.P12, U20.P14, U20.P32, U20.P37, U20.P41, U20.P48
INT: J6.2, R8.P4
INT1: J12.2, R46.P4
INT2: J18.2, R70.P4
INT3: J24.2, R94.P4
unnamed: I2C.1, R23.2
unnamed: D8.C, R24.2
unnamed: I2C.3, R16.2
unnamed: D4.C, R17.2
unnamed: C8.1, FB1.2, R13.1
unnamed: D3.3, J2.A6, J2.B6
unnamed: D3.1, J2.A7, J2.B7
unnamed: PWR.2, R17.1
unnamed: D3.6, R21.1
unnamed: D3.4, R22.1
unnamed: R8.P7, U6.P49
unnamed: R8.P5, U6.P51
unnamed: D10.C, R27.2
unnamed: J2.B5, R14.2
unnamed: J2.A5, R15.2
unnamed: R9.P6, U6.P44
unnamed: R9.P5, U6.P45
unnamed: R8.P8, U6.P46
unnamed: R9.P8, U6.P42
unnamed: R9.P7, U6.P43
unnamed: R10.P1, U6.P27
unnamed: R19.1, RTK.2
unnamed: PPS.2, R18.1
unnamed: D5.C, R18.2
unnamed: D6.C, R19.2
unnamed: R10.P2, U6.P26
unnamed: R11.P2, U6.P19
unnamed: R11.P1, U6.P20
unnamed: R12.1, U6.P53
unnamed: R8.P6, U6.P50
unnamed: R10.P4, U6.P22
unnamed: R10.P3, U6.P23
unnamed: GEO.2, R20.1
unnamed: D7.C, R20.2
unnamed: C4.1, D2.3, R2.2, R6.1
unnamed: I2C1.1, R25.2
unnamed: C3.1, D1.3, R1.2, R5.1
unnamed: I2C1.3, R26.2
unnamed: J9.B5, R29.2
unnamed: J9.A5, R30.2
unnamed: R34.1, RTK1.2
unnamed: PPS1.2, R33.1
unnamed: D13.C, R33.2
unnamed: D14.C, R34.2
unnamed: D11.C, R28.2
unnamed: PWR1.2, R28.1
unnamed: C13.1, FB2.2, R35.1
unnamed: D12.3, J9.A6, J9.B6
unnamed: D12.1, J9.A7, J9.B7
unnamed: D12.6, R31.1
unnamed: D12.4, R32.1
unnamed: R46.P7, U10.P49
unnamed: R46.P5, U10.P51
unnamed: R45.P6, U10.P44
unnamed: R45.P5, U10.P45
unnamed: R46.P8, U10.P46
unnamed: R45.P8, U10.P42
unnamed: R45.P7, U10.P43
unnamed: R47.P1, U10.P27
unnamed: R47.P2, U10.P26
unnamed: R48.P2, U10.P19
unnamed: R48.P1, U10.P20
unnamed: R37.1, U10.P53
unnamed: R46.P6, U10.P50
unnamed: R47.P4, U10.P22
unnamed: R47.P3, U10.P23
unnamed: GEO1.2, R38.1
unnamed: D15.C, R38.2
unnamed: C18.1, D16.3, R39.2, R40.1
unnamed: C17.1, D17.3, R41.2, R42.1
unnamed: D19.C, R51.2
unnamed: I2C2.1, R49.2
unnamed: I2C2.3, R50.2
unnamed: J15.B5, R53.2
unnamed: J15.A5, R54.2
unnamed: R58.1, RTK2.2
unnamed: PPS2.2, R57.1
unnamed: D22.C, R57.2
unnamed: D23.C, R58.2
unnamed: D20.C, R52.2
unnamed: PWR2.2, R52.1
unnamed: C25.1, FB3.2, R59.1
unnamed: D21.3, J15.A6, J15.B6
unnamed: D21.1, J15.A7, J15.B7
unnamed: D21.6, R55.1
unnamed: D21.4, R56.1
unnamed: R70.P7, U15.P49
unnamed: R70.P5, U15.P51
unnamed: R69.P6, U15.P44
unnamed: R69.P5, U15.P45
unnamed: R70.P8, U15.P46
unnamed: R69.P8, U15.P42
unnamed: R69.P7, U15.P43
unnamed: R71.P1, U15.P27
unnamed: R71.P2, U15.P26
unnamed: R72.P2, U15.P19
unnamed: R72.P1, U15.P20
unnamed: R61.1, U15.P53
unnamed: R70.P6, U15.P50
unnamed: R71.P4, U15.P22
unnamed: R71.P3, U15.P23
unnamed: GEO2.2, R62.1
unnamed: D24.C, R62.2
unnamed: C30.1, D25.3, R63.2, R64.1
unnamed: C29.1, D26.3, R65.2, R66.1
unnamed: D28.C, R75.2
unnamed: I2C3.1, R73.2
unnamed: I2C3.3, R74.2
unnamed: J21.B5, R77.2
unnamed: J21.A5, R78.2
unnamed: R82.1, RTK3.2
unnamed: PPS3.2, R81.1
unnamed: D31.C, R81.2
unnamed: D32.C, R82.2
unnamed: D29.C, R76.2
unnamed: PWR3.2, R76.1
unnamed: C37.1, FB4.2, R83.1
unnamed: D30.3, J21.A6, J21.B6
unnamed: D30.1, J21.A7, J21.B7
unnamed: D30.6, R79.1
unnamed: D30.4, R80.1
unnamed: R94.P7, U20.P49
unnamed: R94.P5, U20.P51
unnamed: R93.P6, U20.P44
unnamed: R93.P5, U20.P45
unnamed: R94.P8, U20.P46
unnamed: R93.P8, U20.P42
unnamed: R93.P7, U20.P43
unnamed: R95.P1, U20.P27
unnamed: R95.P2, U20.P26
unnamed: R96.P2, U20.P19
unnamed: R96.P1, U20.P20
unnamed: R85.1, U20.P53
unnamed: R94.P6, U20.P50
unnamed: R95.P4, U20.P22
unnamed: R95.P3, U20.P23
unnamed: GEO3.2, R86.1
unnamed: D33.C, R86.2
unnamed: C42.1, D34.3, R87.2, R88.1
unnamed: C41.1, D35.3, R89.2, R90.1
PPS: D5.A, J6.1, R12.2
PPS1: D13.A, J12.1, R37.2
PPS2: D22.A, J18.1, R61.2
PPS3: D31.A, J24.1, R85.2
RF_IN: D9.2, E1.SIG, FB1.1, U6.P2
RF_IN1: D18.2, E2.SIG, FB2.1, U10.P2
RF_IN2: D27.2, E3.SIG, FB3.1, U15.P2
RF_IN3: D36.2, E4.SIG, FB4.1, U20.P2
RTK_STAT: R11.P8, RTK.1
RTK_STAT1: R48.P8, RTK1.1
RTK_STAT2: R72.P8, RTK2.1
RTK_STAT3: R96.P8, RTK3.1
RXI1: J11.3, R47.P7
RXI2: J7.3, R10.P7
RXI3: J17.3, R71.P7
RXI4: J23.3, R95.P7
RXI/CIPO: J5.5, R9.P2
RXI/CIPO1: J8.5, R45.P2
RXI/CIPO2: J14.5, R69.P2
RXI/CIPO3: J20.5, R93.P2
SCL/CLK: J3.4, J4.4, J5.7, J6.6, R9.P4, R16.1
SCL/CLK1: J1.4, J8.7, J10.4, J12.6, R26.1, R45.P4
SCL/CLK2: J13.4, J14.7, J16.4, J18.6, R50.1, R69.P4
SCL/CLK3: J19.4, J20.7, J22.4, J24.6, R74.1, R93.P4
SDA/!CS: J3.3, J4.3, J5.4, J6.7, R9.P3, R23.1
SDA/!CS1: J1.3, J8.4, J10.3, J12.7, R25.1, R45.P3
SDA/!CS2: J13.3, J14.4, J16.3, J18.7, R49.1, R69.P3
SDA/!CS3: J19.3, J20.4, J22.3, J24.7, R73.1, R93.P3
SHIELD: J2.SHLD1, J2.SHLD2, J2.SHLD3, J2.SHLD4, SHIELD.2
SHIELD1: J9.SHLD1, J9.SHLD2, J9.SHLD3, J9.SHLD4, SHIELD1.2
SHIELD2: J15.SHLD1, J15.SHLD2, J15.SHLD3, J15.SHLD4, SHIELD2.2
SHIELD3: J21.SHLD1, J21.SHLD2, J21.SHLD3, J21.SHLD4, SHIELD3.2
TXO1: J11.2, R47.P8
TXO2: J7.2, R10.P8
TXO3: J17.2, R71.P8
TXO4: J23.2, R95.P8
TXO/COPI: J5.6, R9.P1
TXO/COPI1: J8.6, R45.P1
TXO/COPI2: J14.6, R69.P1
TXO/COPI3: J20.6, R93.P1
TX_READY: J6.5, R8.P1
TX_READY1: J12.5, R46.P1
TX_READY2: J18.5, R70.P1
TX_READY3: J24.5, R94.P1
VIN: C9.1, D3.5, J2.VBUS1, J2.VBUS2, J5.2, U5.1, U5.3
VIN1: C14.1, D12.5, J8.2, J9.VBUS1, J9.VBUS2, U2.1, U2.3
VIN2: C26.1, D21.5, J14.2, J15.VBUS1, J15.VBUS2, U11.1, U11.3
VIN3: C38.1, D30.5, J20.2, J21.VBUS1, J21.VBUS2, U16.1, U16.3
V_BATT: BT2.+, C11.1, R24.1, TP1.1, U6.P36
V_BATT1: BT1.+, C23.1, R27.1, TP2.1, U10.P36
V_BATT2: BT3.+, C35.1, R51.1, TP3.1, U15.P36
V_BATT3: BT4.+, C47.1, R75.1, TP4.1, U20.P36
V_RF: R13.2, U6.P7
V_RF1: R35.2, U10.P7
V_RF2: R59.2, U15.P7
V_RF3: R83.2, U20.P7
WT+: J5.11, R2.1
WT+1: J8.11, R39.1
WT+2: J14.11, R63.1
WT+3: J20.11, R87.1
WT_IN: R6.2, U1.1
WT_IN1: R40.2, U7.1
WT_IN2: R64.2, U12.1
WT_IN3: R88.2, U17.1
WT_INV: R7.1, U1.7, U3.P2
WT_INV1: R43.1, U7.7, U8.P2
WT_INV2: R67.1, U12.7, U13.P2
WT_INV3: R91.1, U17.7, U18.P2
WT_OUT: R10.P5, U3.P4
WT_OUT1: R47.P5, U8.P4
WT_OUT2: R71.P5, U13.P4
WT_OUT3: R95.P5, U18.P4

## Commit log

2020-03-27 Adds breakout board and related documents, libraries
    [SparkFun_GPS_ZED-F9K.brd, SparkFun_GPS_ZED-F9K.sch]
2020-03-27 Movies files out of "breakout" folder
    [SparkFun_GPS_ZED-F9K.brd, SparkFun_GPS_ZED-F9K.sch]
2020-03-27 Renames files to correct module and BoB specification
    [SparkFun_GPS_ZED-F9R_BoB.brd, SparkFun_GPS_ZED-F9R_BoB.sch]
2020-03-27 Renumbers parts, updates parts with PROD_IDs that didn't have them before
    [SparkFun_GPS_ZED-F9R_BoB.brd, SparkFun_GPS_ZED-F9R_BoB.sch]
2020-03-28 Updates silk, fixes RF trace, moves some traces for better clearance
    * Fixes various small design issues
    [SparkFun_GPS_ZED-F9R_BoB.brd, SparkFun_GPS_ZED-F9R_BoB.sch]
2020-03-30 Removes 0402 33 Ohm resistors in place of 33Ohm resistor bank
    [SparkFun_GPS_ZED-F9R_BoB.brd, SparkFun_GPS_ZED-F9R_BoB.sch]
2020-03-30 Fixes packages with over sized tnames and tvalues
    [SparkFun_GPS_ZED-F9R_BoB.brd, SparkFun_GPS_ZED-F9R_BoB.sch]
2020-03-30 Fixes more tvalues and tnames
    [SparkFun_GPS_ZED-F9R_BoB.brd, SparkFun_GPS_ZED-F9R_BoB.sch]
2020-03-31 Adds custom silk
    [SparkFun_GPS_ZED-F9R_BoB.brd]
2020-03-31 Updates all parts to parts in Eagle Libraries
    [SparkFun_GPS_ZED-F9R_BoB.brd, SparkFun_GPS_ZED-F9R_BoB.sch]
2020-03-31 Replaces 910 Ohm resistor with part in Eagle Library
    [SparkFun_GPS_ZED-F9R_BoB.brd, SparkFun_GPS_ZED-F9R_BoB.sch]
2020-03-31 Replaces silk with coool skull
    [SparkFun_GPS_ZED-F9R_BoB.brd]
2020-03-31 Adds panel to files, deletes buzzard labels
    [SparkFun_GPS_ZED-F9R_BoB-Panel.GBL, SparkFun_GPS_ZED-F9R_BoB-Panel.GBO, SparkFun_GPS_ZED-F9R_BoB-Panel.GBP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]
2020-03-31 Adds silk for 3 axes and repanelizes
    [SparkFun_GPS_ZED-F9R_BoB-Panel.brd, SparkFun_GPS_ZED-F9R_BoB.brd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]
2020-04-03 Replaces 0.1uF 6.3V with the 0.1uF 10V X7R capacitors
    [SparkFun_GPS_ZED-F9R_BoB.brd, SparkFun_GPS_ZED-F9R_BoB.sch]
2020-06-16 Fixes silk and repanelizes
    [SparkFun_GPS_ZED-F9R_BoB-Panel.brd, SparkFun_GPS_ZED-F9R_BoB.brd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]
2022-08-18 Updates silk, add new schmitt trigger package and symbol
    * Updates schematic layout
    [ZED-F9R v3.brd, ZED-F9R v3.sch]
2022-08-30 Adds more capacitance to power lines
    * Fixes various trace irregularities
    [ZED-F9R v3.brd, ZED-F9R v3.sch]
2022-08-30 Removes old design files(SparkFun.....), renames new design files (ZED-F9R v3)
    [SparkFun_GPS_ZED-F9R_BoB.brd, SparkFun_GPS_ZED-F9R_BoB.sch, SparkFun_ZED-F9R_v11.brd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]
2022-08-30 Adds new Production files and a few vias to the board design
    [SparkFun_GPS_ZED-F9R_BoB-Panel.GBL, SparkFun_GPS_ZED-F9R_BoB-Panel.GBO, SparkFun_GPS_ZED-F9R_BoB-Panel.GBS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]
2023-06-13 Update README.md
    Adjust link for Arduino Library V3
2023-08-15 Adds u.FL version and moves all design files to their own folders
    [SparkFun_ZED-F9R_v11.brd, SparkFun_ZED-F9R_v11.sch, SparkFun_ZED-F9R_v12_uFL.brd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]
2023-08-15 Adds Production files for u.FL and organizes production folder with version sub-folders
    [SparkFun_ZED-F9R_v11-Panel.GBL, SparkFun_ZED-F9R_v11-Panel.GBO, SparkFun_ZED-F9R_v11-Panel.GBP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]

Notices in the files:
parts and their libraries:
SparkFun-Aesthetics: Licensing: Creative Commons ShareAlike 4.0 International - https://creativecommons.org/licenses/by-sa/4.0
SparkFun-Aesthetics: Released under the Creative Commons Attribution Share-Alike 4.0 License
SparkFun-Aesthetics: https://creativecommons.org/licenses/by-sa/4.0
